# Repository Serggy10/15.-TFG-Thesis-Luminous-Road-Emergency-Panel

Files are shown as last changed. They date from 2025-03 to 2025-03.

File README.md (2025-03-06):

# Description
This folder contains my thesis memory of a luminous road emergency panel, which can be controlled by a touchscreen and wirelessly. It also contains all the code in an appendices folder. An abstract of the memory is the following:

This document describes the process of improving a road emergency panel which was
developed previously in the electronic technology department in the university of
Valladolid. This project arises from the limitations of the previous panel with the
objective of generate clearly message to the road users.
The main characteristics of the project are taken from a market study from which the
selected components will be selected to meet certain objectives of this project.
In this project a microcontroller will be programmed so it can control the emergency
panel according to a user interface on a touch screen. Additionally, an Android
application will be developed to control the device remotely using Bluetooth. All these
systems will be protected by some 3D printed designs.
Keywords
LED panel, ESP32, touch screen, Bluetooth, Android

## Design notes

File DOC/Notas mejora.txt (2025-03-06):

Mejoras:

Panel tactil/ pantalla para indicar todas funcionalidades.
Panel LED en el que mostrar otro tipo de advertencias (viento, accidente...)
Conectividad Bluetooth a parte con app.
Multitensión 12V-24V.
Variador de luminosidad.
LDR compensar luz de noche.
Cambio de luz de control manual a automatico con LDR.

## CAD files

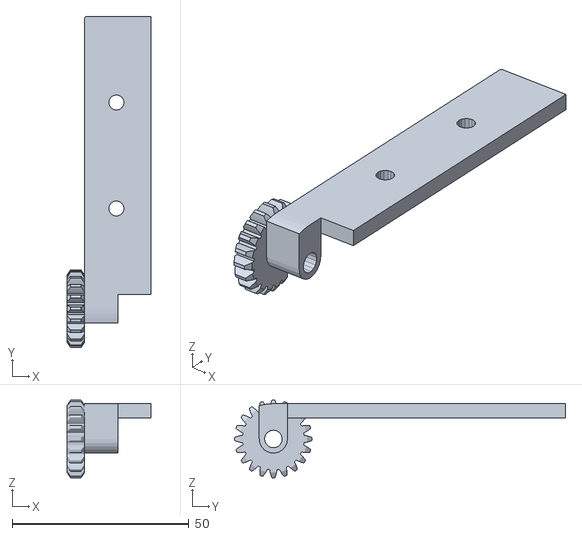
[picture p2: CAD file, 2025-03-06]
Entrega TFG/Anexos/4. Ficheros 3D/EnsamblajeBisagra.stl
23.8 x 93.7 x 22.0

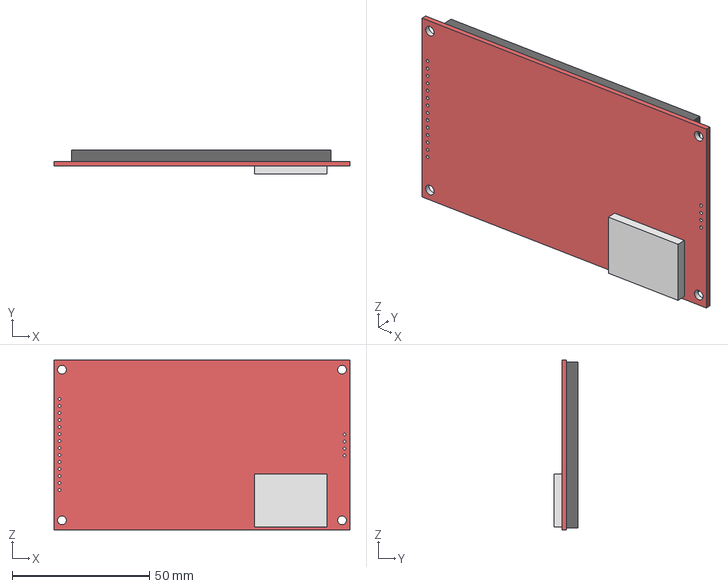
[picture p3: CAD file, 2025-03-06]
Electronica/Proyectos/Panel_Luminoso_V2/LIBRERIAS/ILI9488/ILI9488.stp
108.0 x 8.80 x 61.9 mm

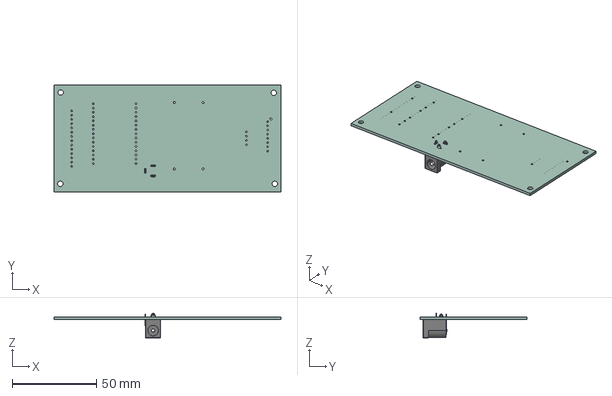
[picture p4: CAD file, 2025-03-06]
Electronica/Proyectos/Panel_Luminoso_V2/Panel_Luminoso_V2_1.step
135.0 x 63.5 x 14.6 mm
BarrelJack_Horizontal
Panel_Luminoso_V2 PCB

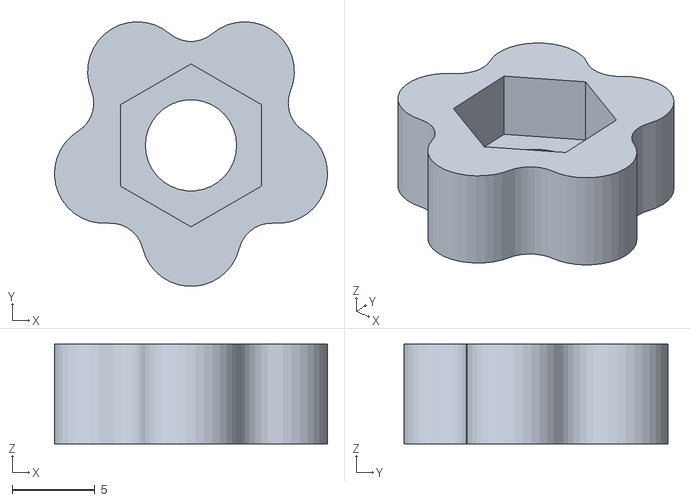
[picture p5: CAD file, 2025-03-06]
Entrega TFG/Anexos/4. Ficheros 3D/Tornillo.stl
16.5 x 15.9 x 6.00

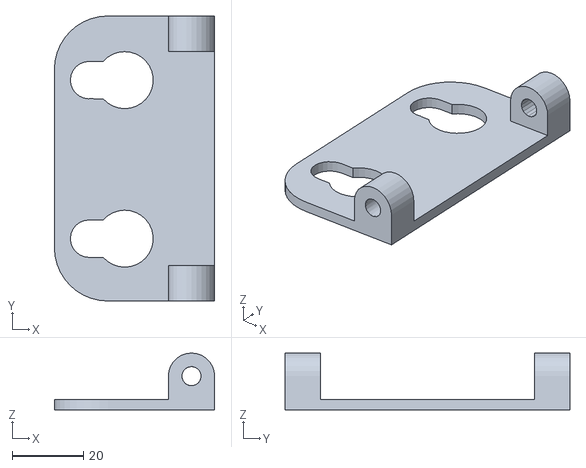
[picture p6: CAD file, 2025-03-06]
Entrega TFG/Anexos/4. Ficheros 3D/Soporte Caja.stl
45.0 x 80.0 x 16.0

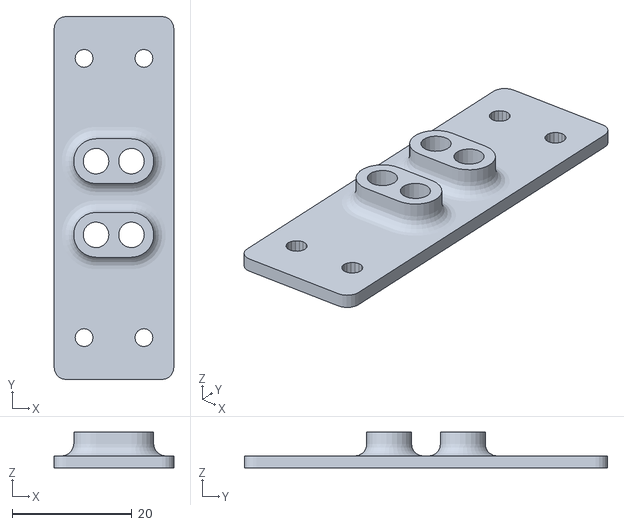
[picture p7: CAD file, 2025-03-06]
Entrega TFG/Anexos/4. Ficheros 3D/Union Soporte Panel.stl
20.0 x 60.7 x 6.00

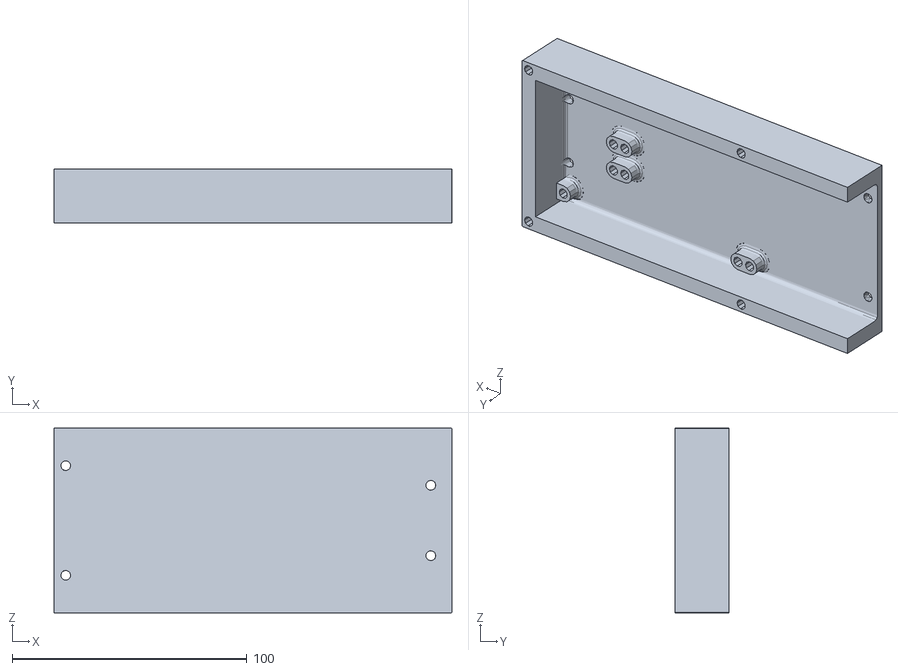
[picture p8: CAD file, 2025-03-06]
Entrega TFG/Anexos/4. Ficheros 3D/Soporte Panel D.stl
169.5 x 23.0 x 78.7

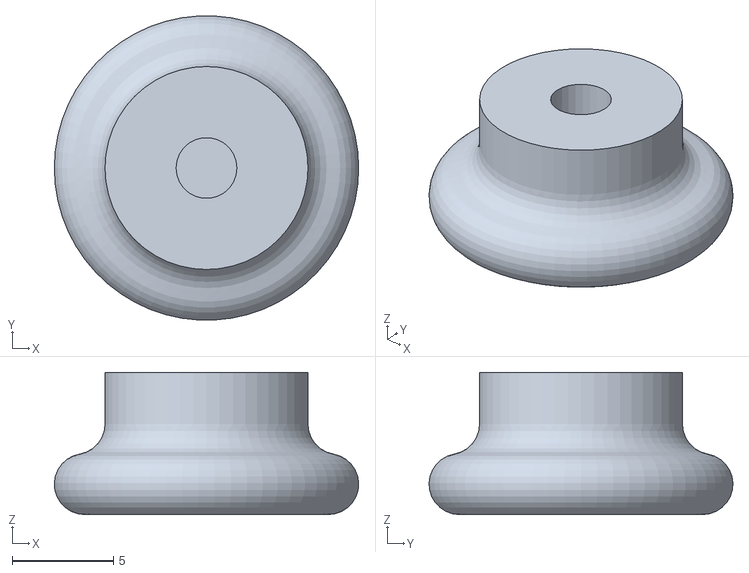
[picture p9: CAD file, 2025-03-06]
Entrega TFG/Anexos/4. Ficheros 3D/Anclajes.stl
15.0 x 15.0 x 7.00

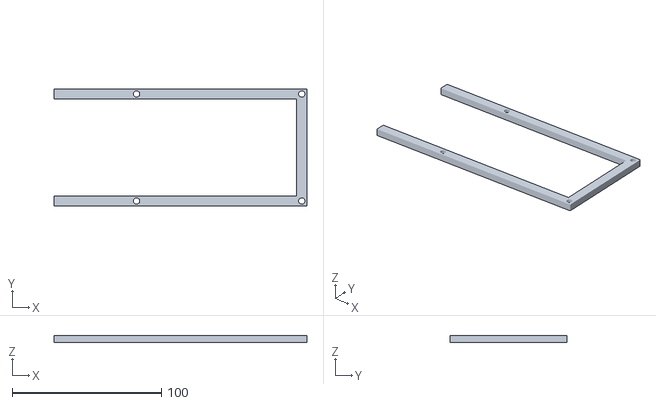
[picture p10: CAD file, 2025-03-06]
Entrega TFG/Anexos/4. Ficheros 3D/ExtensionMarco.stl
169.5 x 78.7 x 5.00

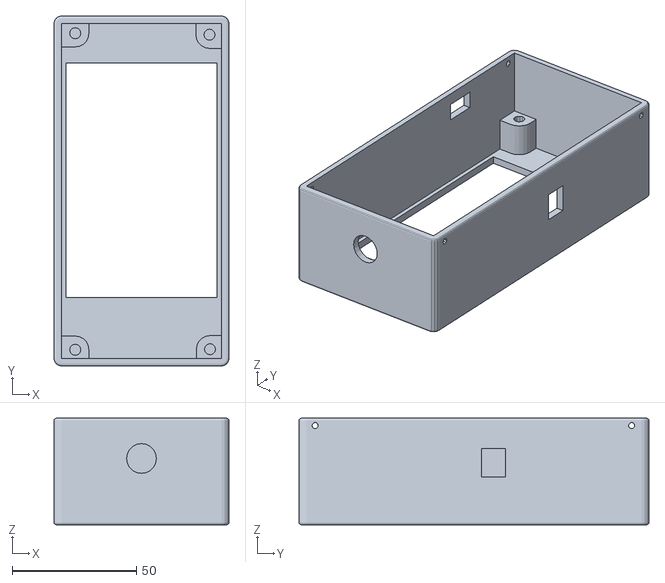
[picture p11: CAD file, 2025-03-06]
Entrega TFG/Anexos/4. Ficheros 3D/Caja.stl
70.5 x 141.0 x 43.0

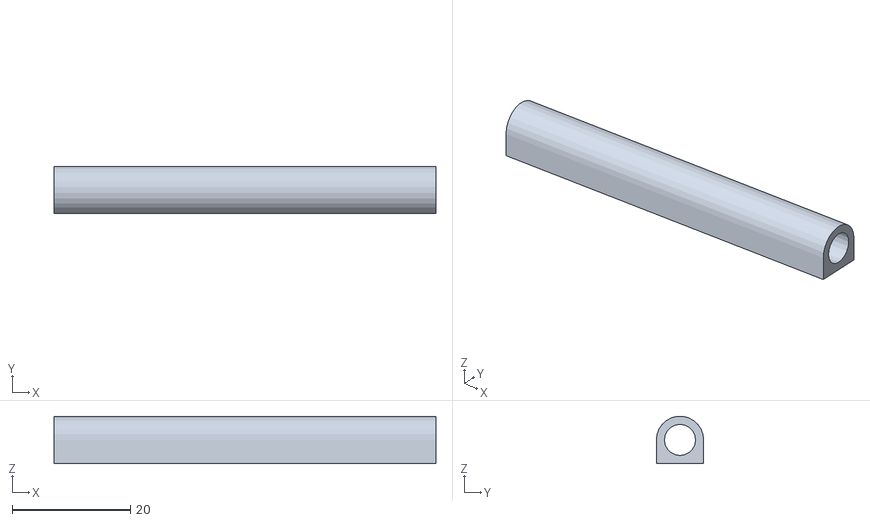
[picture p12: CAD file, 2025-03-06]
Entrega TFG/Anexos/4. Ficheros 3D/Sujeccion Lapiz.stl
64.5 x 8.00 x 7.97

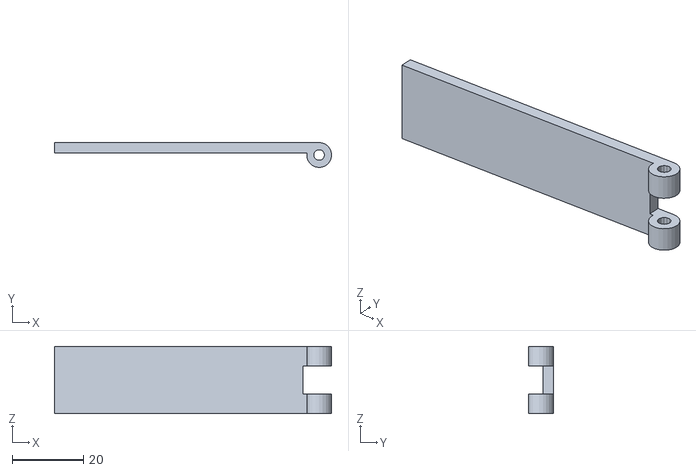
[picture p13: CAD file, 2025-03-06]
Entrega TFG/Anexos/4. Ficheros 3D/Anclaje.stl
77.7 x 7.00 x 18.8

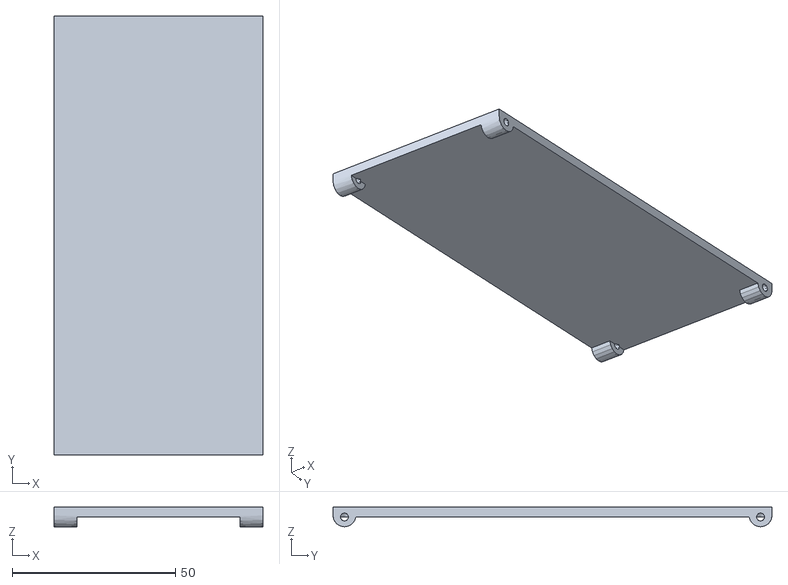
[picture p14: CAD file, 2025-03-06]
Entrega TFG/Anexos/4. Ficheros 3D/Tapa Caja.stl
64.0 x 134.5 x 6.00

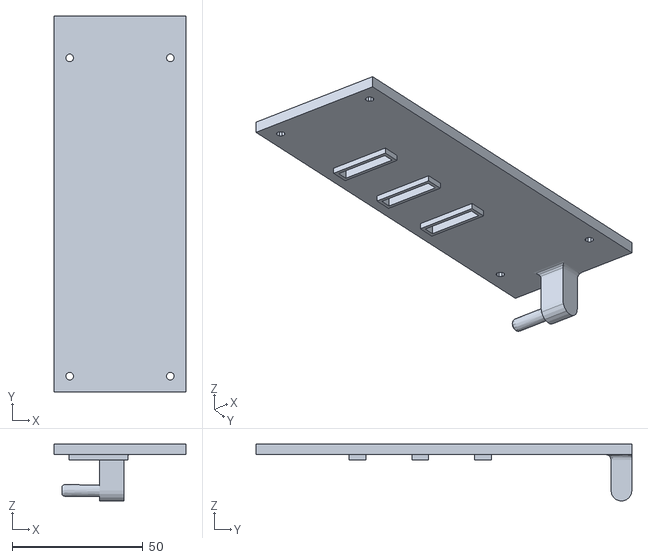
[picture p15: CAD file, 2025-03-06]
Entrega TFG/Anexos/4. Ficheros 3D/BaseIzquierda.stl
50.5 x 143.7 x 21.7

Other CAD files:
Entrega TFG/Anexos/4. Ficheros 3D/BaseSoporte.stl
Entrega TFG/Anexos/4. Ficheros 3D/Soporte Panel I.stl
Electronica/Proyectos/Panel_Luminoso_V2/LIBRERIAS/ILI9488/ExtensionMarco.ipt
Electronica/Proyectos/Panel_Luminoso_V2/LIBRERIAS/ILI9488/ILI9488.dwg
Electronica/Proyectos/Panel_Luminoso_V2/LIBRERIAS/ILI9488/ILI9488.dxf
Electronica/Proyectos/Panel_Luminoso_V2/LIBRERIAS/ILI9488/ILI9488.ipt
Electronica/Proyectos/Panel_Luminoso_V2/LIBRERIAS/ILI9488/Matrices.ipt
Electronica/Proyectos/Panel_Luminoso_V2/LIBRERIAS/ILI9488/OldVersions/ILI9488.0001.dwg
Electronica/Proyectos/Panel_Luminoso_V2/LIBRERIAS/ILI9488/OldVersions/ILI9488.0001.ipt
Electronica/Proyectos/Panel_Luminoso_V2/Panel_Luminoso_V2/BarrelJack_Horizontal.iam
Electronica/Proyectos/Panel_Luminoso_V2/Panel_Luminoso_V2/BarrelJack_Horizontal.ipt
Electronica/Proyectos/Panel_Luminoso_V2/Panel_Luminoso_V2/JST_S3B_XH_A.ipt
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

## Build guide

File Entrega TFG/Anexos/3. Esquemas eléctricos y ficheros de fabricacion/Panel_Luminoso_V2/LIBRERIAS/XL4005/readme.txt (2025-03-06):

++ Module property: Non-isolated step down module(BUCK).	
++ Input voltage:4V-38V	
++ Output voltage:1.25V-36V(adjustable)	
++ Output current:0A-5A,for safe working current, please under 4.5A.	
++ Output power: hingga 75W, lebih dari 50W tambahkan heat sink.	
++ Working temperature:-40degree~+85degree	
++ Working frequency:180KHz	
++ Transfer efficiency:96%(max)	
++ Load regulation rate: S (I) 0.8%	
++ Voltage regulation rate: S (U) 0.8%	
++ Power indicator: yes	
++ Short circuit protection: (current limiting 8A)	
++ Over temperature protection: Yes (automatic shutdown output ultra temperature)	
++ Short circuit protection: Yes	
++ Input reverse connect protection: NO	
++ Output reverse connect protection: no	
++ PCB size:54x24x12mm

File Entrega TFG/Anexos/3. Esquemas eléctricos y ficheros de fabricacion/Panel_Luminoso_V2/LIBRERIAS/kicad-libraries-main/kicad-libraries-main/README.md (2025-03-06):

# Espressif KiCad Library





> Notice: A major update from version 1.0.1 was made to be compliant to the [KLC](https://klc.kicad.org/). Please consider updating your library and checking the symbols and footprints.

> From the version 2.0.0, the library instalation process is done by the PCM.

This repository contains the Symbols, Footprint, and 3D Models for the Espressif SoC and Modules family.

* Notice: The libraries are provided in the hope that they will be useful but without a warranty of any kind.

**The libraries in this repository are intended to be used with KiCad version 7.**

For the KiCad 6 legacy library, please use [this branch](https://github.com/espressif/kicad-libraries/tree/legacy_kicad6) instead.

Each footprint library is stored as a directory with the .pretty suffix. The footprint files are .kicad_mod files within.

## Hardware Design Guidelines

Before designing your hardware, be sure to check all recommendations at:

* [Espressif Hardware Design Guidelines](https://www.espressif.com/sites/default/files/documentation/esp32_hardware_design_guidelines_en.pdf)
* [Espressif Product Selector](https://products.espressif.com/#/)

## Symbols and Footprints

All footprints were designed according to the Recommended PCB Land Pattern section present on each module datasheet.

### SoC

The following SoC are included in this library

| SoC | Symbol | Footprint | Resource |
|:---:|:---:|:---:|:---:|
|ESP32 |Yes |No |[Datasheet](https://www.espressif.com/sites/default/files/documentation/esp32_datasheet_en.pdf) |
|ESP32-PICO-V3 |Yes |No |[Datasheet](https://www.espressif.com/sites/default/files/documentation/esp32-pico-v3_datasheet_en.pdf) |
|ESP32-S2 |Yes |No |[Datasheet](https://www.espressif.com/sites/default/files/documentation/esp32-s2_datasheet_en.pdf) |
|ESP32-C3 |Yes |No |[Datasheet](https://www.espressif.com/sites/default/files/documentation/esp32-c3_datasheet_en.pdf) |
|ESP32-C6 |Yes |No |[Datasheet](https://www.espressif.com/sites/default/files/documentation/esp32-c6_datasheet_en.pdf) |
|ESP32-S3 |Yes |No |[Datasheet](https://www.espressif.com/sites/default/files/documentation/esp32-s3_datasheet_en.pdf) |
|ESP8286 |Yes |No |[Datasheet](https://www.espressif.com/sites/default/files/documentation/0a-esp8266ex_datasheet_en.pdf)  |
|ESP8285 |Yes |No |[Datasheet](https://www.espressif.com/sites/default/files/documentation/0a-esp8285_datasheet_en.pdf) |
|ESP8684 (ESP32-C2) |Yes |No |[Datasheet](https://www.espressif.com/sites/default/files/documentation/esp8684_datasheet_en.pdf) |
|ESP8685 |Yes |No |[Datasheet](https://www.espressif.com/sites/default/files/documentation/esp8685_datasheet_en.pdf) |

### Modules

| Module | Symbol | Footprint | Resource |
|:---:|:---:|:---:|:---:|
|ESP32-WROOM-32E |Yes |Yes |[Datasheet](https://www.espressif.com/sites/default/files/documentation/esp32-wroom-32e_esp32-wroom-32ue_datasheet_en.pdf) |
|ESP32-WROOM-32UE  |Yes |Yes |[Datasheet](https://www.espressif.com/sites/default/files/documentation/esp32-wroom-32e_esp32-wroom-32ue_datasheet_en.pdf) |
|ESP32-WROOM-DA |Yes |Yes |[Datasheet](https://www.espressif.com/sites/default/files/documentation/esp32-wroom-da_datasheet_en.pdf) |
|ESP32-WROVER-E |Yes |Yes |[Datasheet](https://www.espressif.com/sites/default/files/documentation/esp32-wrover-e_esp32-wrover-ie_datasheet_en.pdf) |
|ESP32-MINI-1 |Yes |Yes |[Datasheet](https://www.espressif.com/sites/default/files/documentation/esp32-mini-1_datasheet_en.pdf) |
|ESP32-MINI-1U |Yes |Yes |[Datasheet](https://www.espressif.com/sites/default/files/documentation/esp32-mini-1_datasheet_en.pdf) |
|ESP32-C3-MINI-1 |Yes |Yes |[Datasheet](https://www.espressif.com/sites/default/files/documentation/esp32-c3-mini-1_datasheet_en.pdf) |
|ESP32-C3-WROOM-02 |Yes |Yes |[Datasheet](https://www.espressif.com/sites/default/files/documentation/esp32-c3-wroom-02_datasheet_en.pdf) |
|ESP32-C6-MINI-1 |Yes |Yes |[Datasheet](https://www.espressif.com/sites/default/files/documentation/esp32-c6-mini-1_datasheet_en.pdf) |
|ESP32-C6-MINI-1U  |Yes |Yes |[Datasheet](https://www.espressif.com/sites/default/files/documentation/esp32-c6-mini-1_datasheet_en.pdf) |
|ESP32-C6-WROOM-1  |Yes |Yes |[Datasheet](https://www.espressif.com/sites/default/files/documentation/esp32-c6-wroom-1_datasheet_en.pdf) |
|ESP32-S2-MINI-1 |Yes |Yes |[Datasheet](https://www.espressif.com/sites/default/files/documentation/esp32-s2-mini-1_esp32-s2-mini-1u_datasheet_en.pdf) |
|ESP32-S2-MINI-1U  |Yes |Yes |[Datasheet](https://www.espressif.com/sites/default/files/documentation/esp32-s2-mini-1_esp32-s2-mini-1u_datasheet_en.pdf) |
|ESP32-S2-SOLO |Yes |Yes |[Datasheet](https://www.espressif.com/sites/default/files/documentation/esp32-s2-solo_esp32-s2-solo-u_datasheet_en.pdf) |
|ESP32-S2-SOLO-2U  |Yes |Yes |[Datasheet](https://www.espressif.com/sites/default/files/documentation/esp32-s2-solo-2_esp32-s2-solo-2u_datasheet_en.pdf) |
|ESP32-S2-WROOM |Yes |Yes |[Datasheet](https://www.espressif.com/sites/default/files/documentation/esp32-s2-wroom_esp32-s2-wroom-i_datasheet_en.pdf) |
|ESP32-S2-WROVER |Yes |Yes |[Datasheet](https://www.espressif.com/sites/default/files/documentation/esp32-s2-wrover_esp32-s2-wrover-i_datasheet_en.pdf)  |
|ESP32-S3-MINI-1 |Yes |Yes |[Datasheet](https://www.espressif.com/sites/default/files/documentation/esp32-s3-mini-1_mini-1u_datasheet_en.pdf) |
|ESP32-S3-MINI-1U  |Yes |Yes |[Datasheet](https://www.espressif.com/sites/default/files/documentation/esp32-s3-mini-1_mini-1u_datasheet_en.pdf) |
|ESP32-S3-WROOM-1  |Yes |Yes |[Datasheet](https://www.espressif.com/sites/default/files/documentation/esp32-s3-wroom-1_wroom-1u_datasheet_en.pdf) |
|ESP32-S3-WROOM-1U |Yes |Yes |[Datasheet](https://www.espressif.com/sites/default/files/documentation/esp32-s3-wroom-1_wroom-1u_datasheet_en.pdf) |
|ESP32-S3-WROOM-2  |Yes |Yes |[Datasheet](https://www.espressif.com/sites/default/files/documentation/esp32-s3-wroom-2_datasheet_en.pdf) |

### Development Boards

| Dev Board | Symbol | Footprint | Resource |
|:---:|:---:|:---:|:---:|
|ESP32-S2-Saola-1 |Yes |Yes |[Schematic](https://dl.espressif.com/dl/schematics/ESP32-S2-SAOLA-1_V1.1_schematics.pdf) |
|ESP32-S2-DevKitC-1|Yes |Yes |[Schematic](https://dl.espressif.com/dl/schematics/esp-idf/SCH_ESP32-S2-DEVKITC-1_V1_20220817.pdf) |
|ESP32-DevKitC |Yes |Yes |[Schematic](https://dl.espressif.com/dl/schematics/esp32_devkitc_v4-sch.pdf) |
|ESP32-S3-DevKitC |Yes |Yes |[Schematic](https://dl.espressif.com/dl/schematics/SCH_ESP32-S3-DevKitC-1_V1.1_20220413.pdf) |
|ESP32-S2-DevKitM |Yes |Yes |[Schematic](https://dl.espressif.com/dl/schematics/ESP32-S2-DevKitM-1_V1_Schematics.pdf) |
|ESP32-C6-DevKitC-1|Yes |Yes |[Schematic](https://docs.espressif.com/projects/espressif-esp-dev-kits/en/latest/_static/esp32-c6-devkitc-1/schematics/esp32-c6-devkitc-1-schematics_v1.2.pdf) |

## Manual Installation - PCM

The Espressif KiCad library is distributed via the Pluguin and Content Manager (PCM) and the installation is done automatically.

To install the library, you need to download the **"espressif-kicad-addon.zip"** file from the latest release. For legacy support, please visit the legacy branch and follow the instructions from there.

* [Latest Release](https://github.com/espressif/kicad-libraries/releases/latest)

For KiCad 6 and 7, you can use the following steps:

1. On KiCad, open the PCM in the main KiCad window.

First Step

2. The PCM window will display a list of available plugins, libraries, and color themes. You can browse through the categories or use the search bar to find a specific package.

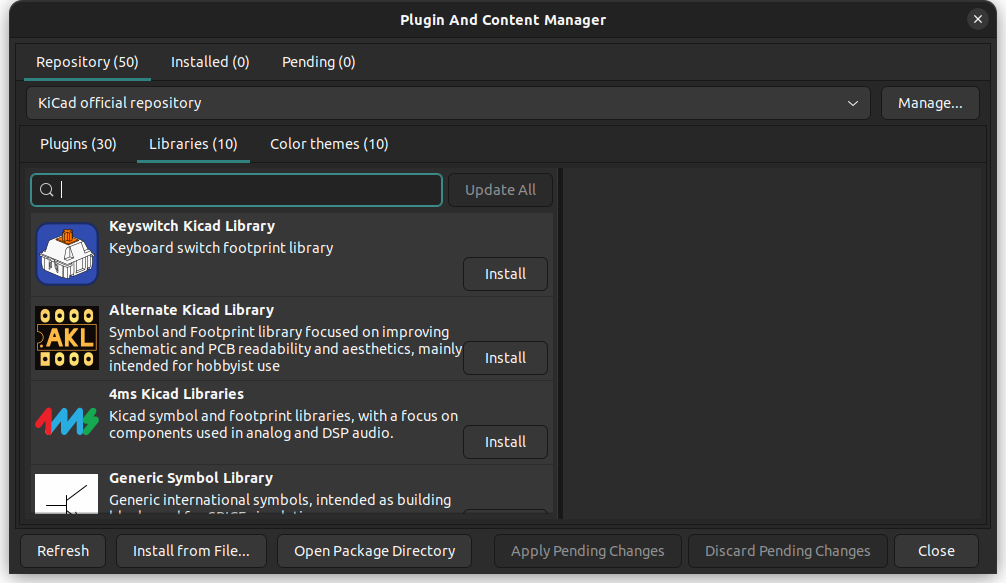
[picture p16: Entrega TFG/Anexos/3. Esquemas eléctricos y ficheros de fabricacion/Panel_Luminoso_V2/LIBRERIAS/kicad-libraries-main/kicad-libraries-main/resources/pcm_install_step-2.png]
First Step


3. To install the library manually using the ZIP file from the latest release, you need to select the file from **"Install from file..."**

First Step

4. Once the package is installed, you will see the Espressif Library listed on the Installed tab.

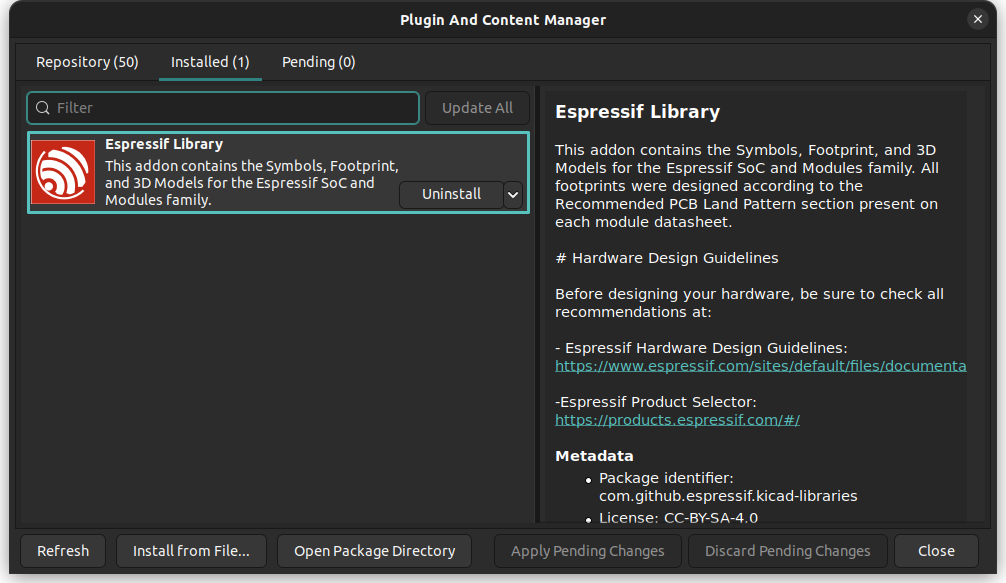
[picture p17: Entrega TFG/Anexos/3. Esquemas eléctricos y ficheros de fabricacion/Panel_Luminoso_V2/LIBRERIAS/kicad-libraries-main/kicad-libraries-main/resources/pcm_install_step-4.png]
First Step


5. Now you are ready to use the library. Note that the library will be listed as **PCM_Espressif** in the Symbol and Footprint.

## Contributing

If you want to contribute, please consider sending us a Pull Request (PR).

### About KiCad

KiCad is a Cross-Platform and Open Source Electronics Design Automation Suite. See [KiCad EDA](https://kicad.org/) for more information.

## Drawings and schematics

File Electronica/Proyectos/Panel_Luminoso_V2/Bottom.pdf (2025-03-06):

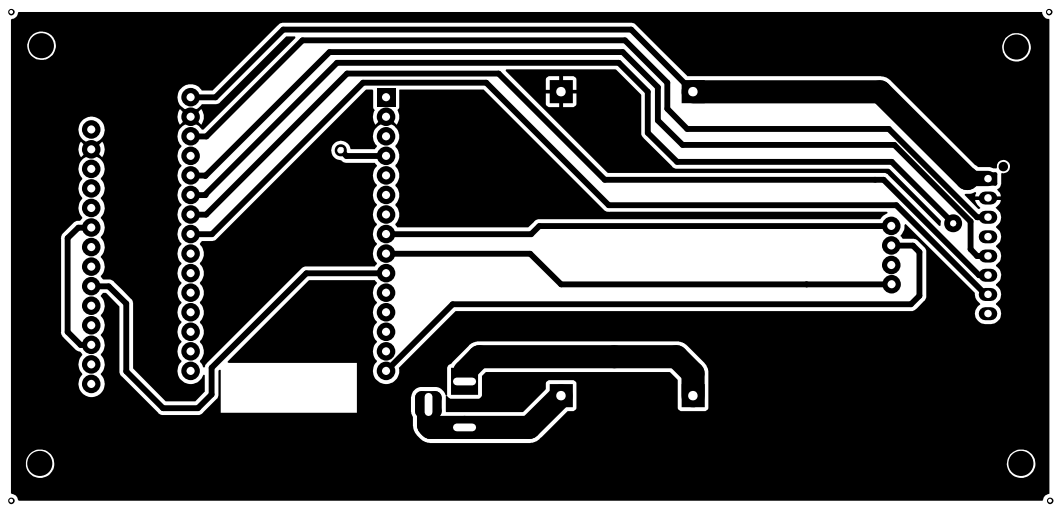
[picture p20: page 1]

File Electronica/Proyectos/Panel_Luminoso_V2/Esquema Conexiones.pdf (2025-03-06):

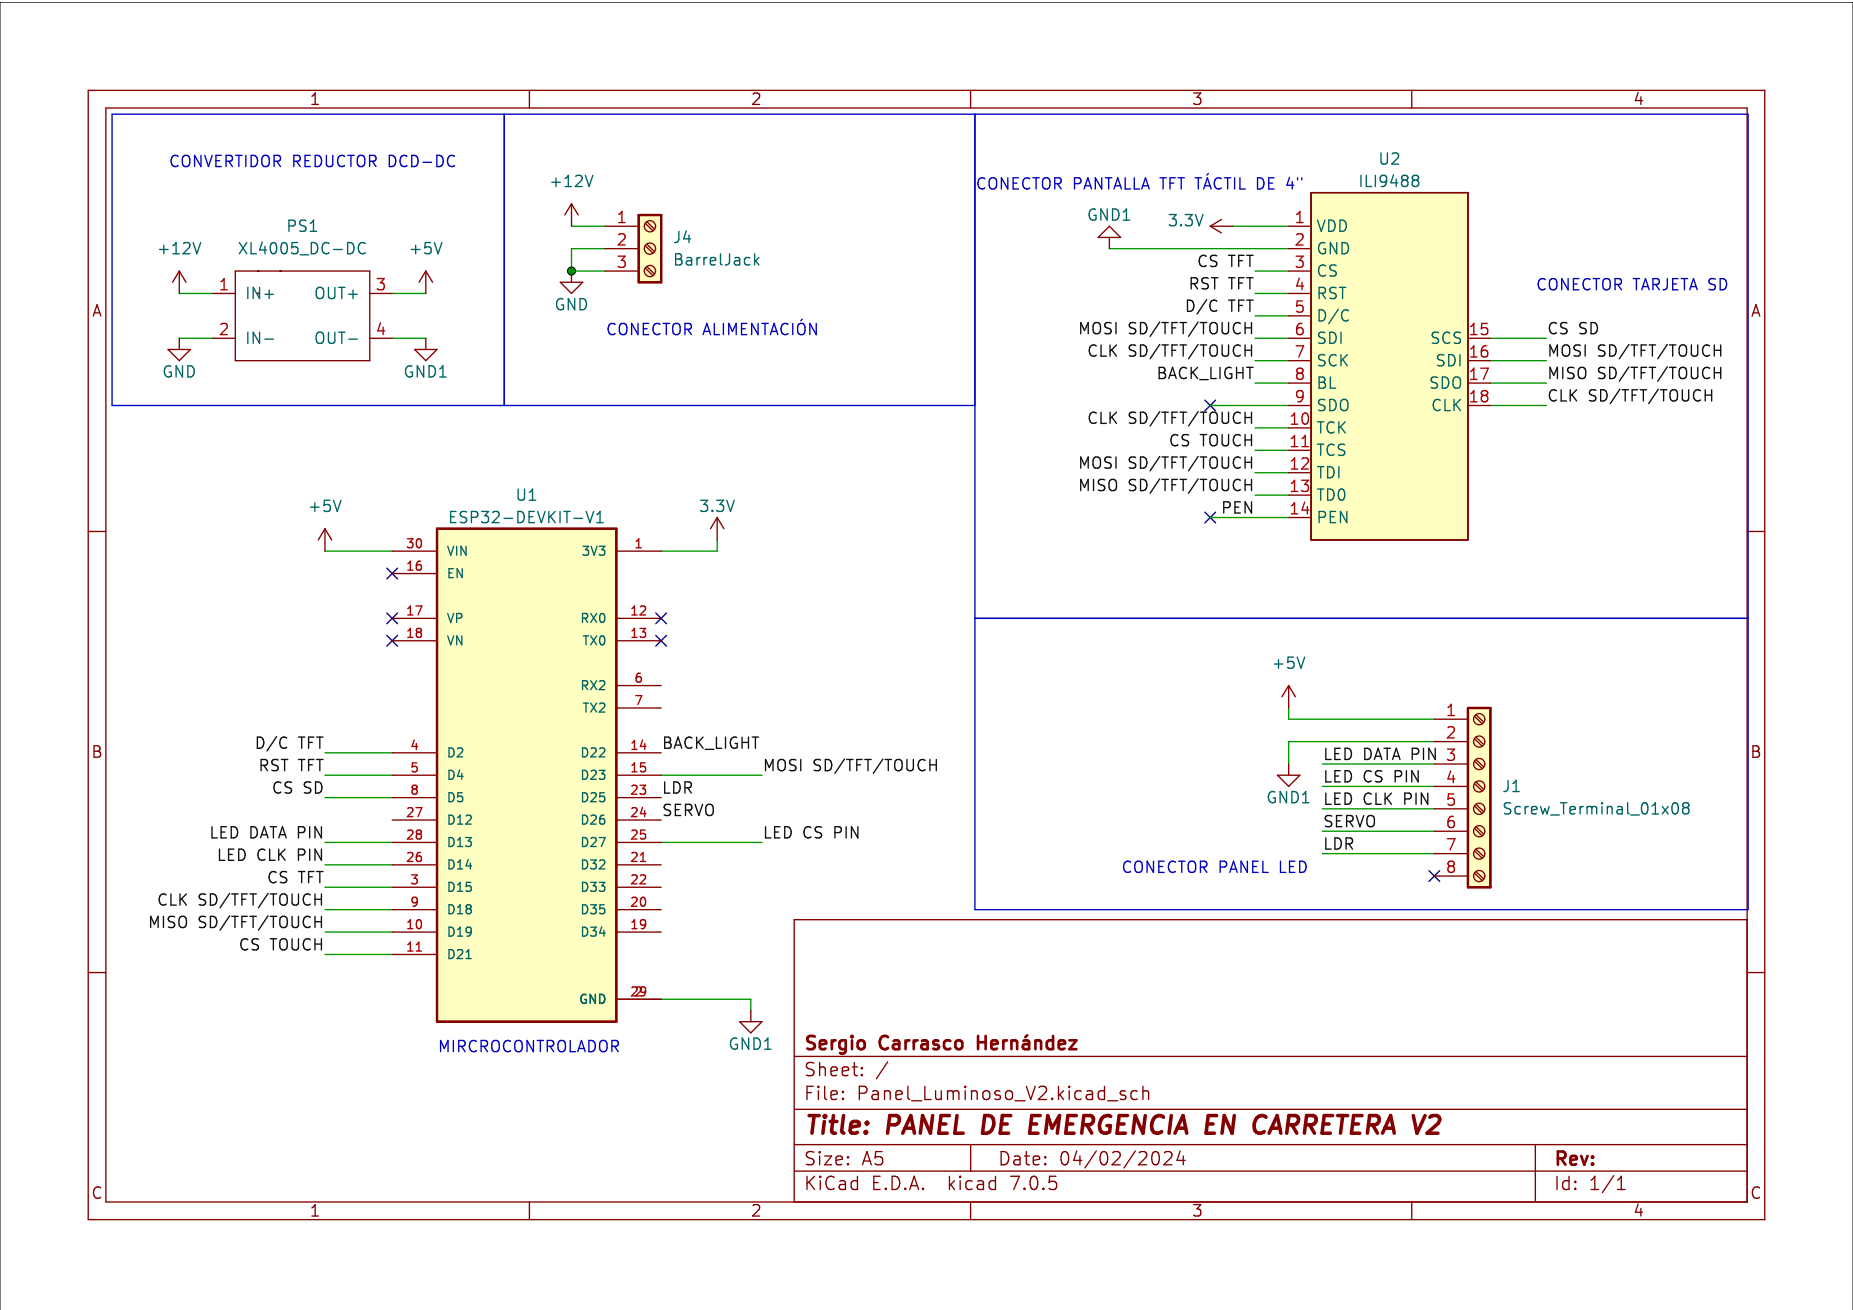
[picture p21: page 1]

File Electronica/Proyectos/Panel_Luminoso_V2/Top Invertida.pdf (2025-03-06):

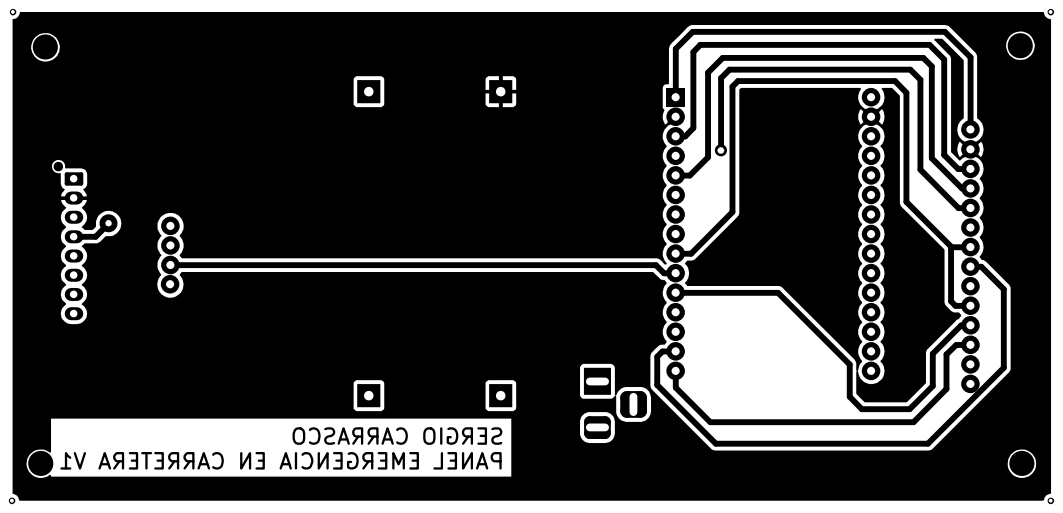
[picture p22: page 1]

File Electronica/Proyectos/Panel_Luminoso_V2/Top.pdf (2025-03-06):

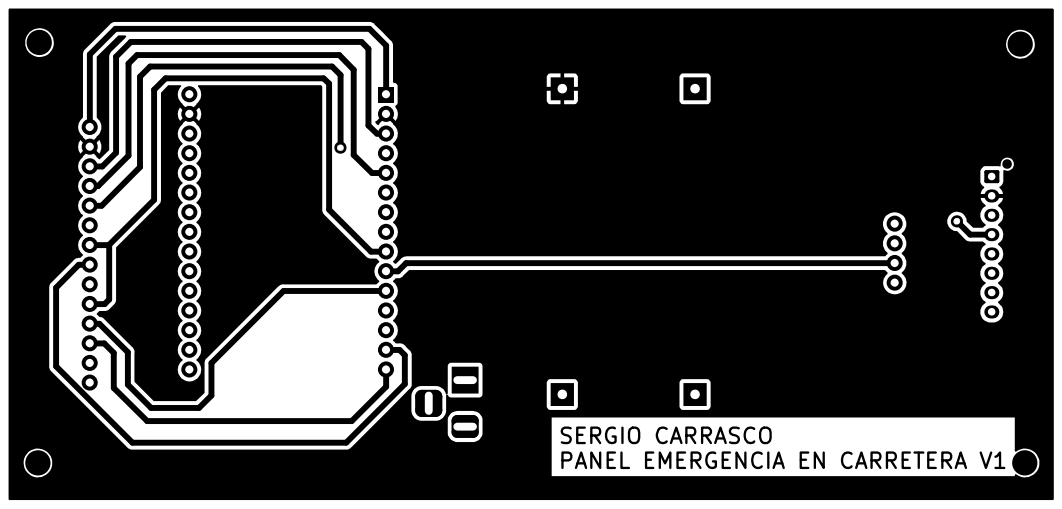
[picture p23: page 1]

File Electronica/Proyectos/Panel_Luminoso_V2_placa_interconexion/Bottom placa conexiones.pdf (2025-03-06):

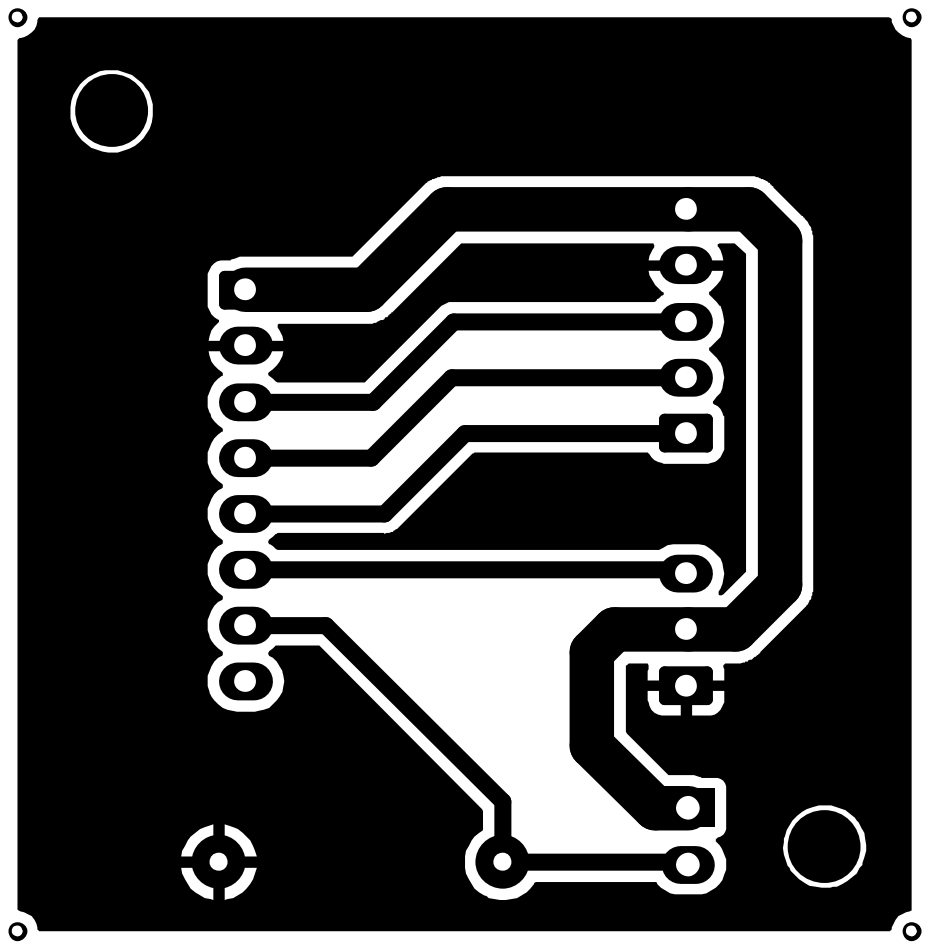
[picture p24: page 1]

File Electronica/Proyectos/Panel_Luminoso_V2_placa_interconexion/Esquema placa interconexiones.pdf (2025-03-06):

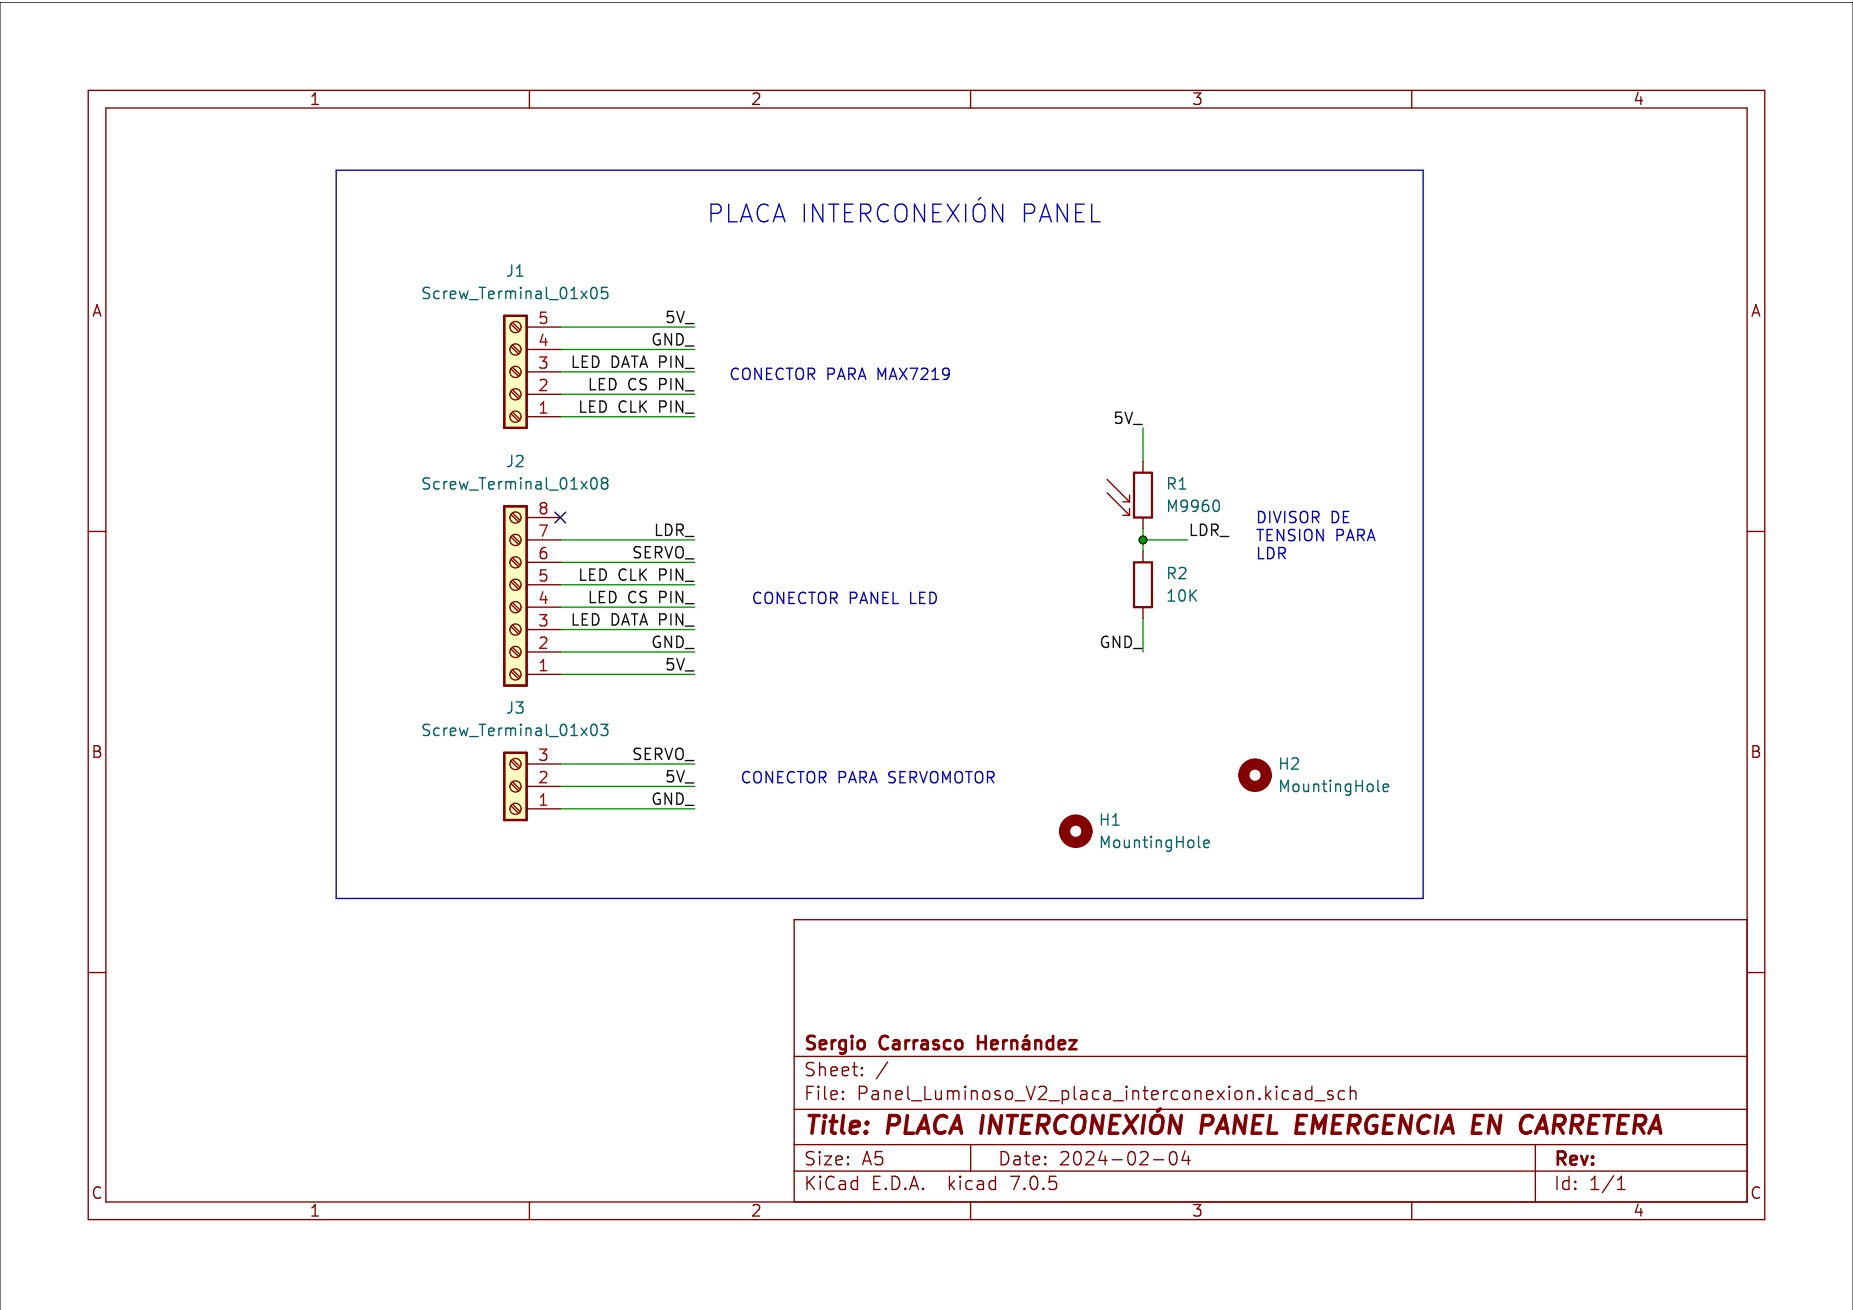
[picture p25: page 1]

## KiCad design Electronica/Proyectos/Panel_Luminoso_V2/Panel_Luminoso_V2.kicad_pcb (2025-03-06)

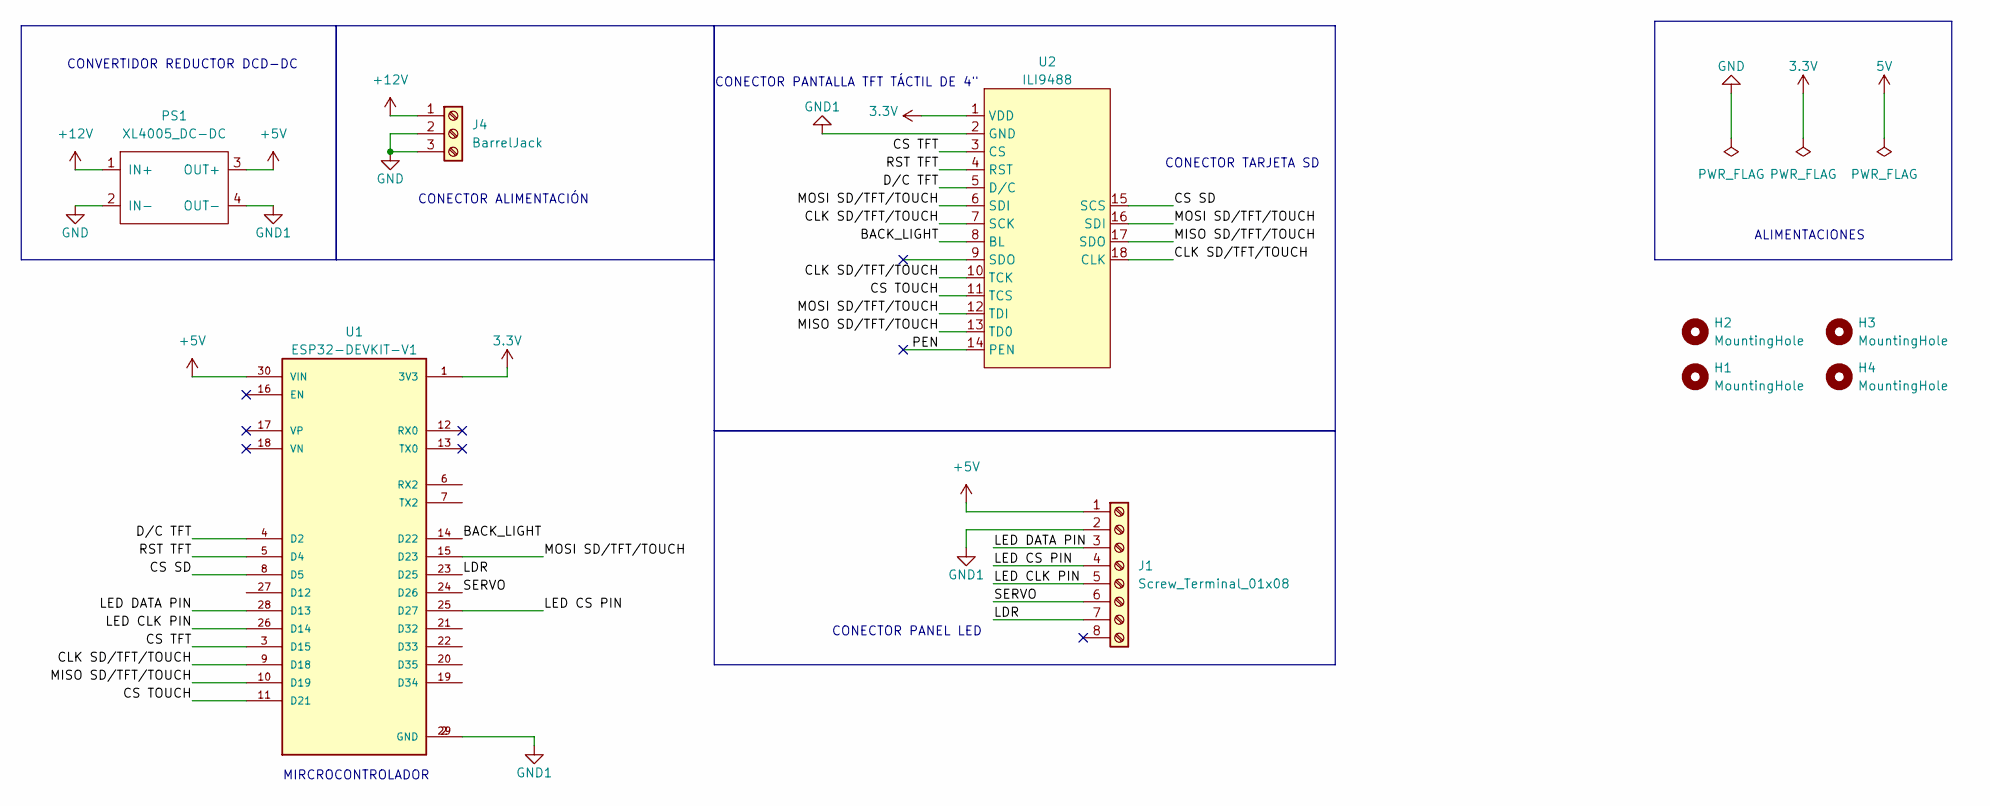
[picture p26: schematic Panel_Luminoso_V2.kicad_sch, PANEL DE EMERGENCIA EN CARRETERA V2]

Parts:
H1, H2, H3, H4: MountingHole; MountingHole_3.2mm_M3
J1: Screw_Terminal_01x08; JST_XH_B8B-XH-AM_1x08_P2.50mm_Vertical
J4: BarrelJack; BarrelJack_Horizontal
PS1: XL4005_DC-DC; XL4005_DC-DC_SinAgujeros
U1: ESP32-DEVKIT-V1; MODULE_ESP32_DEVKIT_V1_SinAgujeros; PARTREV N/A
U2: ILI9488

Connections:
+5V: J1.1, PS1.3 (OUT+), U1.30 (VIN)
+12V: J4.1, PS1.1 (IN+)
/BACK_LIGHT: U1.14 (D22), U2.8 (BL)
/CLK SD/TFT/TOUCH: U1.9 (D18), U2.7 (SCK), U2.10 (TCK), U2.18 (CLK)
/CS SD: U1.8 (D5), U2.15 (SCS)
/CS TFT: U1.3 (D15), U2.3 (CS)
/CS TOUCH: U1.11 (D21), U2.11 (TCS)
/D/C TFT: U1.4 (D2), U2.5 (D/C)
/LDR: J1.7, U1.23 (D25)
/LED CLK PIN: J1.5, U1.26 (D14)
/LED CS PIN: J1.4, U1.25 (D27)
/LED DATA PIN: J1.3, U1.28 (D13)
/MISO SD/TFT/TOUCH: U1.10 (D19), U2.13 (TD0), U2.17 (SDO)
/MOSI SD/TFT/TOUCH: U1.15 (D23), U2.6 (SDI), U2.12 (TDI), U2.16 (SDI)
/PEN: U2.14 (PEN)
/RST TFT: U1.5 (D4), U2.4 (RST)
/SERVO: J1.6, U1.24 (D26)
GND: J4.2, J4.3, PS1.2 (IN-)
GND1: J1.2, PS1.4 (OUT-), U1.2 (GND), U1.29 (GND), U2.2 (GND)
VCC: U1.1 (3V3), U2.1 (VDD)

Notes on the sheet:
CONECTOR ALIMENTACIÓN
CONECTOR TARJETA SD
MIRCROCONTROLADOR
CONECTOR PANTALLA TFT TÁCTIL DE 4"
ALIMENTACIONES
CONVERTIDOR REDUCTOR DCD-DC
CONECTOR PANEL LED

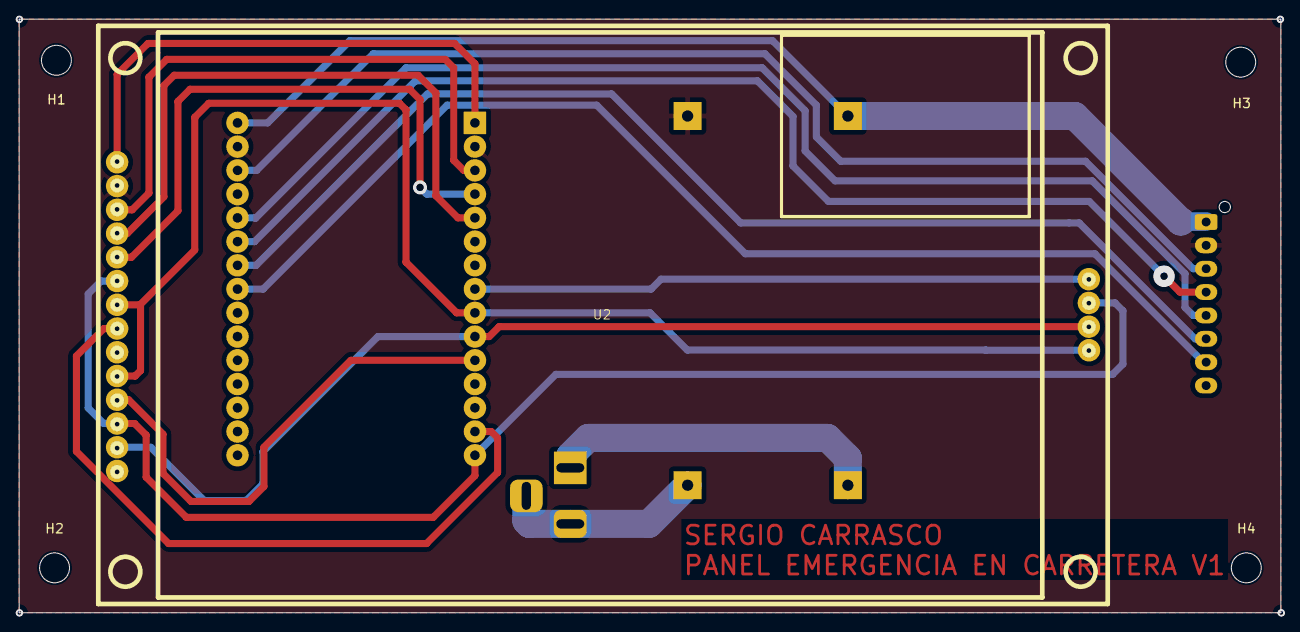
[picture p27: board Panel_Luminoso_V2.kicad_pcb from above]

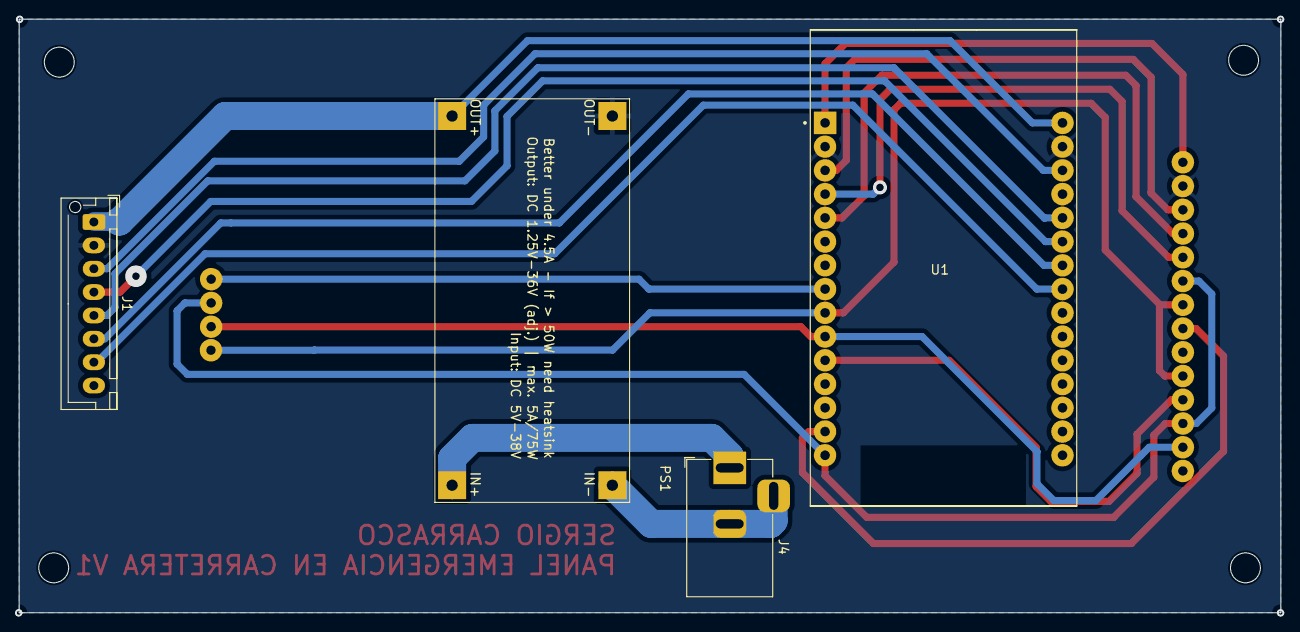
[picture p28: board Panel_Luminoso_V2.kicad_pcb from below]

Board: 2 copper layers, 135.0 x 63.5 mm, 9 parts (4 on the bottom side), 19 nets.

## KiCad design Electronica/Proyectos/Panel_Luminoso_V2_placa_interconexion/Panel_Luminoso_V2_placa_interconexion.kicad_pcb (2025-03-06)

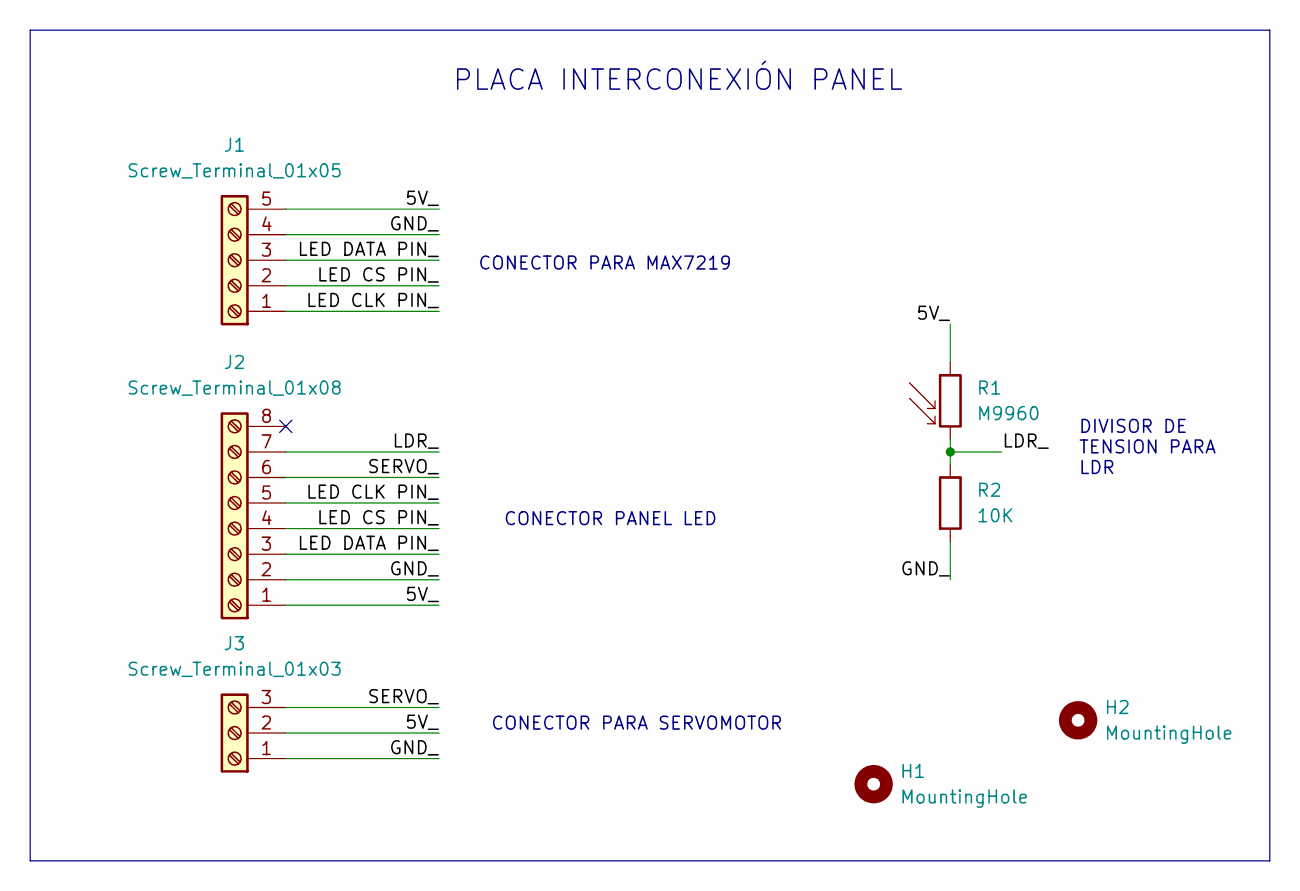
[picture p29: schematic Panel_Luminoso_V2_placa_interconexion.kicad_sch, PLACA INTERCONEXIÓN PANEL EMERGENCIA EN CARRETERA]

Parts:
H1, H2: MountingHole; MountingHole_3.2mm_M3
J1: Screw_Terminal_01x05; JST_XH_S5B-XH-A_1x05_P2.50mm_Horizontal
J2: Screw_Terminal_01x08; JST_XH_S8B-XH-A_1x08_P2.50mm_Horizontal
J3: Screw_Terminal_01x03; JST_XH_S3B-XH-A_1x03_P2.50mm_Horizontal
R1: M9960; PinSocket_1x02_P2.54mm_Vertical
R2: 10K; R_Axial_DIN0309_L9.0mm_D3.2mm_P12.70mm_Horizontal

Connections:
/5V_: J1.5, J2.1, J3.2, R1.1
/GND_: J1.4, J2.2, J3.1, R2.2
/LDR_: J2.7, R1.2, R2.1
/LED CLK PIN_: J1.1, J2.5
/LED CS PIN_: J1.2, J2.4
/LED DATA PIN_: J1.3, J2.3
/SERVO_: J2.6, J3.3

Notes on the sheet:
CONECTOR PANEL LED
CONECTOR PARA MAX7219
PLACA INTERCONEXIÓN PANEL
DIVISOR DE TENSION PARA LDR
CONECTOR PARA SERVOMOTOR

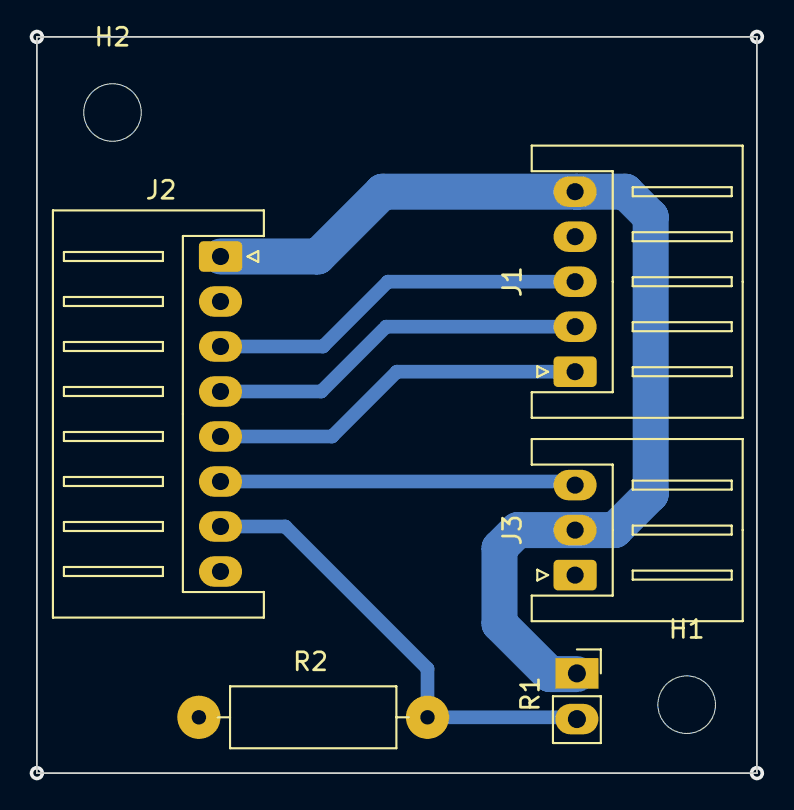
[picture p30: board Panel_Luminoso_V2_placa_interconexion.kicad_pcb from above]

Board: 2 copper layers, 40.0 x 40.9 mm, 7 parts (0 on the bottom side), 7 nets.

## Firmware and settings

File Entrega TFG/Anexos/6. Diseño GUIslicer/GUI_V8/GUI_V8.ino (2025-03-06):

//<App !Start!>
// FILE: [GUI_V8.ino]
// Created by GUIslice Builder version: [0.17.b24]
//
// GUIslice Builder Generated File
//
// For the latest guides, updates and support view:
// https://github.com/ImpulseAdventure/GUIslice
//
//<App !End!>

// ------------------------------------------------
// Headers to include
// ------------------------------------------------
#include "GUI_V8_GSLC.h"
#include "Addons/XRingGauge.h"
//#include "Addons/XCheckbox.h"
#include <FS.h>

TFT_eSPI tft = TFT_eSPI();

#define CALIBRATION_FILE "/TouchCalData1"  // Fichero donde se guardan los archivos de calibración.

bool REPEAT_CAL = false;  // Si se desea repetir la calibración se debe cambiar a true.

void touch_calibrate() {
  uint16_t calData[5];
  uint8_t calDataOK = 0;

  if (!SPIFFS.begin())  // Comprobación de la existencia del sistema de ficheros. Si no existe se formatea la memoria SPIFFS.
  {
    Serial.println("Formatting file system");
    SPIFFS.format();
    SPIFFS.begin();
  }

  if (SPIFFS.exists(CALIBRATION_FILE))  // Comprobación de la existencia del fichero de calibración. Si existe se puede sobreescribir si se desea.
  {
    if (REPEAT_CAL) {
      // Delete if we want to re-calibrate
      SPIFFS.remove(CALIBRATION_FILE);
    } else {
      fs::File f = SPIFFS.open(CALIBRATION_FILE, "r");
      if (f) {
        if (f.readBytes((char*)calData, 14) == 14)
          calDataOK = 1;
        f.close();
      }
    }
  }

  if (calDataOK && !REPEAT_CAL)  // Si los datos son correctos y no se desea repetir la calibración se cargan los datos en la patalla TFT.
  {
    tft.setTouch(calData);
  } else  // Si no se empieza de nuevo la calibración.
  {
    tft.fillScreen(TFT_BLACK);
    tft.setCursor(20, 0);
    tft.setTextFont(2);
    tft.setTextSize(1);
    tft.setTextColor(TFT_WHITE, TFT_BLACK);
    tft.println("Toque las esquinas indicadas");
    tft.setTextFont(1);
    tft.println();

    if (REPEAT_CAL) {
      tft.setTextColor(TFT_RED, TFT_BLACK);
    }
    //
    tft.calibrateTouch(calData, TFT_MAGENTA, TFT_BLACK, 15);  // Función para calibrar la pantalla.
    gslc_SetTouchRemapCal(&m_gui, calData[0], calData[1], calData[2], calData[3]);

    Serial.println(calData[0]);
    Serial.println(calData[1]);
    Serial.println(calData[2]);
    Serial.println(calData[3]);
    Serial.println(calData[4]);

    tft.setTextColor(TFT_GREEN, TFT_BLACK);
    tft.println("Calibración completada!");

    fs::File f = SPIFFS.open(CALIBRATION_FILE, "w");  // Se guardan los datos en la memoria SPIFFS.
    if (f) {
      f.write((const unsigned char*)calData, 14);
      f.close();
    }
  }
}


// ------------------------------------------------
// Program Globals
// ------------------------------------------------

// Save some element references for direct access
//<Save_References !Start!>
gslc_tsElemRef* ArcoInclinacion   = NULL;
gslc_tsElemRef* BarraIluminacionPantalla= NULL;
gslc_tsElemRef* BarraIluminacionPersonalizadaPanel= NULL;
gslc_tsElemRef* BarraInclinacion  = NULL;
gslc_tsElemRef* BarraListaEfectos = NULL;
gslc_tsElemRef* BarraListaEfectosInferior= NULL;
gslc_tsElemRef* BarraListaEfectosSuperior= NULL;
gslc_tsElemRef* BarraMensajesDinamicos= NULL;
gslc_tsElemRef* BarraMensajesTexto= NULL;
gslc_tsElemRef* BarraVelocidadInferior= NULL;
gslc_tsElemRef* BarraVelocidadPersonalizada= NULL;
gslc_tsElemRef* BarraVelocidadSuperior= NULL;
gslc_tsElemRef* BotonAutoIluminacionPanel= NULL;
gslc_tsElemRef* CirculoLogo       = NULL;
gslc_tsElemRef* EntradaTextoInferior= NULL;
gslc_tsElemRef* EntradaTextoSuperior= NULL;
gslc_tsElemRef* ListaEfectos      = NULL;
gslc_tsElemRef* ListaEfectosInferior= NULL;
gslc_tsElemRef* ListaEfectosSuperior= NULL;
gslc_tsElemRef* ListaMensajesDinamico= NULL;
gslc_tsElemRef* ListaMensajesTexto= NULL;
gslc_tsElemRef* TextoPersonalizado= NULL;
gslc_tsElemRef* VariableEstadoActual= NULL;
gslc_tsElemRef* VariableTextoLuzAmbiente= NULL;
gslc_tsElemRef* m_pElemKeyPadAlpha= NULL;
//<Save_References !End!>

// Define debug message function
static int16_t DebugOut(char ch) {
  if (ch == (char)'\n') Serial.println("");
  else Serial.write(ch);
  return 0;
}

// ------------------------------------------------
// Callback Methods
// ------------------------------------------------
// Common Button callback
bool CbBtnCommon(void* pvGui, void* pvElemRef, gslc_teTouch eTouch, int16_t nX, int16_t nY) {
  // Typecast the parameters to match the GUI and element types
  gslc_tsGui* pGui = (gslc_tsGui*)(pvGui);
  gslc_tsElemRef* pElemRef = (gslc_tsElemRef*)(pvElemRef);
  gslc_tsElem* pElem = gslc_GetElemFromRef(pGui, pElemRef);

  if (eTouch == GSLC_TOUCH_UP_IN) {
    // From the element's ID we can determine which button was pressed.
    switch (pElem->nId) {
//<Button Enums !Start!>
      case BotonMenuMensajesTexto:
        gslc_SetPageCur(&m_gui, MenuMensajesTexto);
        break;
      case BotonMenuEfectosDinamicos:
        gslc_SetPageCur(&m_gui, MenuEfectosDinamicos);
        break;
      case BotonMenuInclinacionPanel:
        gslc_SetPageCur(&m_gui, MenuInclinacionPanel);
        break;
      case BotonMenuIluminacionPanel:
        gslc_SetPageCur(&m_gui, MenuIluminacionPanel);
        break;
      case BotonMenuAjustes:
        gslc_SetPageCur(&m_gui, MenuAjustes);
        break;
      case BotonMenuMensajePersonalizado:
        gslc_SetPageCur(&m_gui, MenuMensajePersonalizado);
        break;
      case E_BotonApagar:
        break;
      case BotonVolver1:
        gslc_SetPageCur(&m_gui, E_MenuPrincipal);
        break;
      case BotonVolver2:
        gslc_SetPageCur(&m_gui, E_MenuPrincipal);
        break;
      case BotonVolver3:
        gslc_SetPageCur(&m_gui, E_MenuPrincipal);
        break;
      case BotonHome:
        pElemRef = gslc_PageFindElemById(pGui, MenuInclinacionPanel, E_ArcoInclinacion);
        gslc_ElemXRingGaugeSetVal(pGui, pElemRef, 0);
        pElemRef = gslc_PageFindElemById(pGui, MenuInclinacionPanel, E_BarraInclinacion);
        gslc_ElemXSeekbarSetPos(pGui, pElemRef, 0);
        break;
      case Boton90:
        pElemRef = gslc_PageFindElemById(pGui, MenuInclinacionPanel, E_ArcoInclinacion);
        gslc_ElemXRingGaugeSetVal(pGui, pElemRef, 90);
        pElemRef = gslc_PageFindElemById(pGui, MenuInclinacionPanel, E_BarraInclinacion);
        gslc_ElemXSeekbarSetPos(pGui, pElemRef, 90);
        break;
      case Boton45:
        pElemRef = gslc_PageFindElemById(pGui, MenuInclinacionPanel, E_ArcoInclinacion);
        gslc_ElemXRingGaugeSetVal(pGui, pElemRef, 45);
        pElemRef = gslc_PageFindElemById(pGui, MenuInclinacionPanel, E_BarraInclinacion);
        gslc_ElemXSeekbarSetPos(pGui, pElemRef, 45);
        break;
      case Boton135:
        pElemRef = gslc_PageFindElemById(pGui, MenuInclinacionPanel, E_ArcoInclinacion);
        gslc_ElemXRingGaugeSetVal(pGui, pElemRef, 135);
        pElemRef = gslc_PageFindElemById(pGui, MenuInclinacionPanel, E_BarraInclinacion);
        gslc_ElemXSeekbarSetPos(pGui, pElemRef, 135);
        break;
      case BotonVolver4:
        gslc_SetPageCur(&m_gui, E_MenuPrincipal);
        break;
      case E_BotonCalibrado:
        REPEAT_CAL = true;
        touch_calibrate();  // Comprobación de si la pantalla necesita una calibración o no.
        InitGUIslice_gen();
        break;
      case BotonVolver5:
        gslc_SetPageCur(&m_gui, E_MenuPrincipal);
        break;
      case E_TextoPersonalizado:
        // Clicked on edit field, so show popup box and associate with this text field
        gslc_ElemXKeyPadInputAsk(&m_gui, m_pElemKeyPadAlpha, E_POP_KEYPAD_ALPHA, TextoPersonalizado);
        break;
      case E_BotonDosFilas:
        gslc_SetPageCur(&m_gui, MenuMensajePersonalizadoDos);
        break;
      case BotonVolver6:
        gslc_SetPageCur(&m_gui, E_MenuPrincipal);
        break;
      case E_BotonAutoIluminacionPanel:
        // TODO Add code for Toggle button ON/OFF state
        if (gslc_ElemXTogglebtnGetState(&m_gui, BotonAutoIluminacionPanel)) {
          ;
        }
        break;
      case E_EntradaTextoSuperior:
        // Clicked on edit field, so show popup box and associate with this text field
        gslc_ElemXKeyPadInputAsk(&m_gui, m_pElemKeyPadAlpha, E_POP_KEYPAD_ALPHA, EntradaTextoSuperior);
        break;
      case E_EntradaTextoInferior:
        // Clicked on edit field, so show popup box and associate with this text field
        gslc_ElemXKeyPadInputAsk(&m_gui, m_pElemKeyPadAlpha, E_POP_KEYPAD_ALPHA, EntradaTextoInferior);
        break;
      case E_BotonVolverUnaFila:
        gslc_SetPageCur(&m_gui, MenuMensajePersonalizado);
        break;
//<Button Enums !End!>
      default:
        break;
    }
  }
  return true;
}


// KeyPad Input Ready callback
bool CbKeypad(void* pvGui, void* pvElemRef, int16_t nState, void* pvData) {
  gslc_tsGui* pGui = (gslc_tsGui*)pvGui;
  gslc_tsElemRef* pElemRef = (gslc_tsElemRef*)(pvElemRef);
  gslc_tsElem* pElem = gslc_GetElemFromRef(pGui, pElemRef);

  // From the pvData we can get the ID element that is ready.
  int16_t nTargetElemId = gslc_ElemXKeyPadDataTargetIdGet(pGui, pvData);
  if (nState == XKEYPAD_CB_STATE_DONE) {
    // User clicked on Enter to leave popup
    // - If we have a popup active, pass the return value directly to
    //   the corresponding value field
    switch (nTargetElemId) {
//<Keypad Enums !Start!>

      case E_TextoPersonalizado:
        gslc_ElemXKeyPadInputGet(pGui, TextoPersonalizado, pvData);
        gslc_PopupHide(&m_gui);
        break;
      case E_EntradaTextoSuperior:
        gslc_ElemXKeyPadInputGet(pGui, EntradaTextoSuperior, pvData);
        gslc_PopupHide(&m_gui);
        break;
      case E_EntradaTextoInferior:
        gslc_ElemXKeyPadInputGet(pGui, EntradaTextoInferior, pvData);
        gslc_PopupHide(&m_gui);
        break;
//<Keypad Enums !End!>
      default:
        break;
    }
  } else if (nState == XKEYPAD_CB_STATE_CANCEL) {
    // User escaped from popup, so don't update values
    gslc_PopupHide(&m_gui);
  }
  return true;
}
//<Spinner Callback !Start!>
//<Spinner Callback !End!>
bool CbListbox(void* pvGui, void* pvElemRef, int16_t nSelId) {
  gslc_tsGui* pGui = (gslc_tsGui*)(pvGui);
  gslc_tsElemRef* pElemRef = (gslc_tsElemRef*)(pvElemRef);
  gslc_tsElem* pElem = gslc_GetElemFromRef(pGui, pElemRef);
  char acTxt[MAX_STR + 1];

  if (pElemRef == NULL) {
    return false;
  }

  // From the element's ID we can determine which listbox was active.
  switch (pElem->nId) {
//<Listbox Enums !Start!>

    case E_ListaEfectos:
      if (nSelId != XLISTBOX_SEL_NONE) {
        gslc_ElemXListboxGetItem(&m_gui, pElemRef, nSelId, acTxt, MAX_STR);
      }
      break;
    case E_ListaEfectosSuperior:
      if (nSelId != XLISTBOX_SEL_NONE) {
        gslc_ElemXListboxGetItem(&m_gui, pElemRef, nSelId, acTxt, MAX_STR);
      }
      break;
    case E_ListaEfectosInferior:
      if (nSelId != XLISTBOX_SEL_NONE) {
        gslc_ElemXListboxGetItem(&m_gui, pElemRef, nSelId, acTxt, MAX_STR);
      }
      break;
    case E_ListaMensajesTexto:
      if (nSelId != XLISTBOX_SEL_NONE) {
        gslc_ElemXListboxGetItem(&m_gui, pElemRef, nSelId, acTxt, MAX_STR);
      }
      break;
    case E_ListaMensajesDinamicos:
      if (nSelId != XLISTBOX_SEL_NONE) {
        gslc_ElemXListboxGetItem(&m_gui, pElemRef, nSelId, acTxt, MAX_STR);
      }
      break;
//<Listbox Enums !End!>
    default:
      break;
  }
  return true;
}
//<Draw Callback !Start!>
//<Draw Callback !End!>


// Callback function for when a slider's position has been updated
bool CbSlidePos(void* pvGui, void* pvElemRef, int16_t nPos) {
  gslc_tsGui* pGui = (gslc_tsGui*)(pvGui);
  gslc_tsElemRef* pElemRef = (gslc_tsElemRef*)(pvElemRef);
  gslc_tsElem* pElem = gslc_GetElemFromRef(pGui, pElemRef);
  int16_t nVal;


  // From the element's ID we can determine which slider was updated.
  switch (pElem->nId) {
//<Slider Enums !Start!>

    case E_BarraInclinacion:
      // Fetch the slider position
      nVal = gslc_ElemXSeekbarGetPos(pGui, BarraInclinacion);
      pElemRef = gslc_PageFindElemById(pGui, MenuInclinacionPanel, E_ArcoInclinacion);
      gslc_ElemXRingGaugeSetVal(pGui, pElemRef, nVal);

      break;
    case E_BarraIluminacionPersonalizadaPanel:
      // Fetch the slider position
      nVal = gslc_ElemXSeekbarGetPos(pGui, BarraIluminacionPersonalizadaPanel);
      pElemRef = gslc_PageFindElemById(pGui, MenuIluminacionPanel, E_BotonAutoIluminacionPanel);
      gslc_ElemXTogglebtnSetState(pGui, pElemRef, false);
      break;
    case E_BarraListaEfectos:
      // Fetch the slider position
      nVal = gslc_ElemXSliderGetPos(pGui, BarraListaEfectos);
      Serial.println("BarraListaEfectos:" + String(nVal));
      pElemRef = gslc_PageFindElemById(pGui, MenuMensajePersonalizado, E_ListaEfectos);
      gslc_ElemXListboxSetScrollPos(pGui, pElemRef, 2 * nVal);
      break;
    case E_BarraVelocidadPersonalizada:
      // Fetch the slider position
      nVal = gslc_ElemXSeekbarGetPos(pGui, BarraVelocidadPersonalizada);
      break;
    case E_BarraListaEfectosSuperior:
      // Fetch the slider position
      nVal = gslc_ElemXSliderGetPos(pGui, BarraListaEfectosSuperior);
      pElemRef = gslc_PageFindElemById(pGui, MenuMensajePersonalizadoDos, E_ListaEfectosSuperior);
      gslc_ElemXListboxSetScrollPos(pGui, pElemRef, nVal);
      break;
    case E_BarraVelocidadSuperior:
      // Fetch the slider position
      nVal = gslc_ElemXSeekbarGetPos(pGui, BarraVelocidadSuperior);
      break;
    case E_BarraVelocidadInferior:
      // Fetch the slider position
      nVal = gslc_ElemXSeekbarGetPos(pGui, BarraVelocidadSuperior);
      break;
    case E_BarraListaEfectosInferior:
      // Fetch the slider position
      nVal = gslc_ElemXSliderGetPos(pGui, BarraListaEfectosInferior);
      pElemRef = gslc_PageFindElemById(pGui, MenuMensajePersonalizadoDos, E_ListaEfectosInferior);
      gslc_ElemXListboxSetScrollPos(pGui, pElemRef, nVal);
      break;
    case E_BarraIluminacionPantalla:
      // Fetch the slider position
      nVal = gslc_ElemXSliderGetPos(pGui, pElemRef);
      analogWrite(22, map(nVal, 1, 10, 10, 255));
      break;
    case E_BarraMensajesTexto:
      // Fetch the slider position
      nVal = gslc_ElemXSliderGetPos(pGui, BarraMensajesTexto);
      pElemRef = gslc_PageFindElemById(pGui, MenuMensajesTexto, E_ListaMensajesTexto);
      gslc_ElemXListboxSetScrollPos(pGui, pElemRef, nVal);
      break;
    case E_BarraMensajesDinamicos:
      // Fetch the slider position
      nVal = gslc_ElemXSliderGetPos(pGui, BarraMensajesDinamicos);
      pElemRef = gslc_PageFindElemById(pGui, MenuEfectosDinamicos, E_ListaMensajesDinamicos);
      gslc_ElemXListboxSetScrollPos(pGui, pElemRef, nVal);
      break;
//<Slider Enums !End!>
    default:
      break;
  }

  return true;
}
//<Tick Callback !Start!>
//<Tick Callback !End!>

void setup() {
  // ------------------------------------------------
  // Initialize
  // ------------------------------------------------
  Serial.begin(9600);
  pinMode(22, OUTPUT);
  analogWrite(22, 10);
  // Wait for USB Serial
  //delay(1000);  // NOTE: Some devices require a delay after Serial.begin() before serial port can be used

  gslc_InitDebug(&DebugOut);

  // ------------------------------------------------
  // Create graphic elements
  // ------------------------------------------------
  InitGUIslice_gen();
  tft.init();                       // Inicializa la pantalla TFT.
  tft.setRotation(1);               // Se puede cambiar la rotación de la pantalla.
  touch_calibrate();                // Comprobación de si la pantalla necesita una calibración o no.
  tft.fillScreen(TFT_BLACK);        // Se rellena la pantalla en color negro para eliminar imagenes anteriores.
  tft.setFreeFont(&FreeMono9pt7b);  // Establece la fuente de la pantalla
}

// -----------------------------------
// Main event loop
// -----------------------------------
void loop() {

  // ------------------------------------------------
  // Update GUI Elements
  // ------------------------------------------------

  //TODO - Add update code for any text, gauges, or sliders

  // ------------------------------------------------
  // Periodically call GUIslice update function
  // ------------------------------------------------
  gslc_Update(&m_gui);
}
